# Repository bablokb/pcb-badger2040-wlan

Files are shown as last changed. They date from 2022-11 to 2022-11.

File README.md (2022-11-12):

pcb-badger2040-wlan
===================

A small pcb that allows to add an ESP-01S and/or PCF8523-RTC-breakout
to the back of a Pimoroni Badger2040 (or Tufty2040):

  - Badger2040 with SMD-pins:  
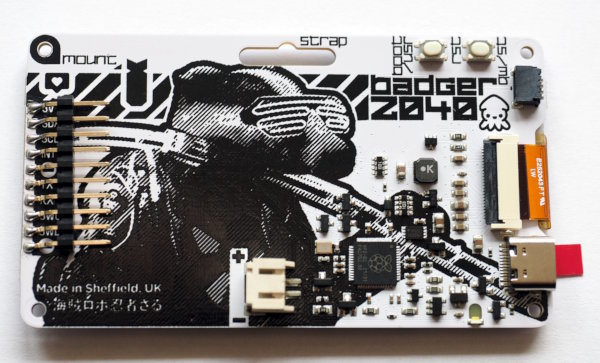
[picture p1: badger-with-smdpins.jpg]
    

  - PCB added:  
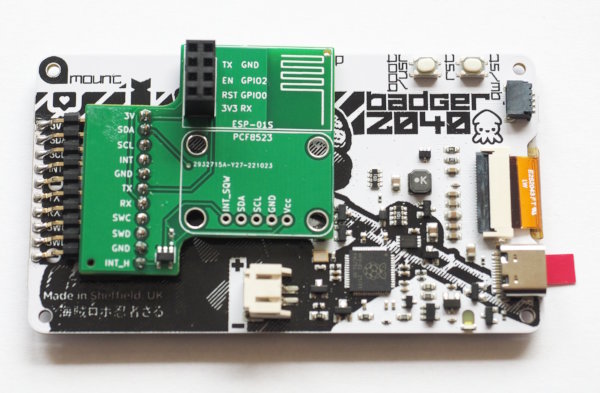
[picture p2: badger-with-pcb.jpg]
    

  - ESP-01S connected:  
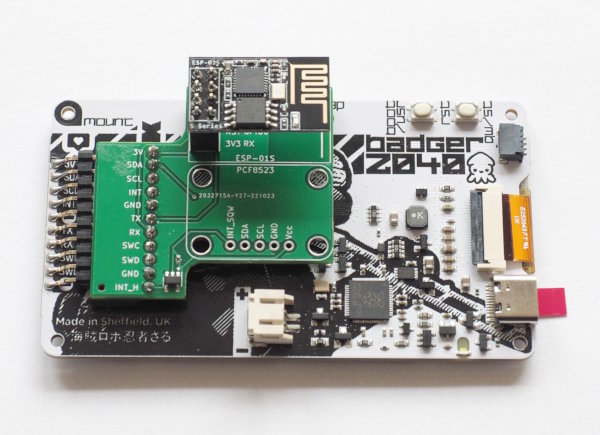
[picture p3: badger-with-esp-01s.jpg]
    

  - Additionally with RTC (PCF8523):  
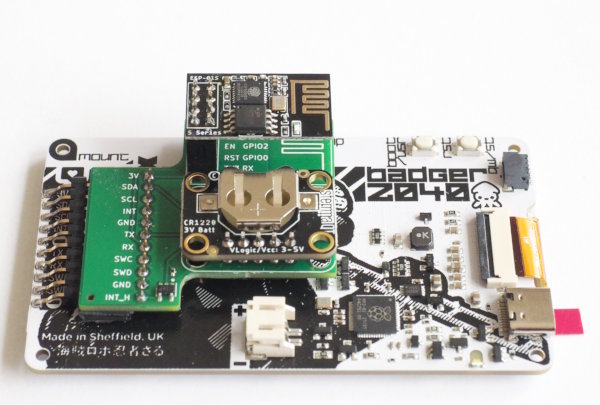
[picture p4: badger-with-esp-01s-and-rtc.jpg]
    

Note that the images show an old Rev 3 version of the PCB.

Design-Files
------------

KiCAD source files are in `badger-2040-wlan.kicad`. Production files
for JLCPCB are in directory `production`. Since the pcb does not
need any SMD-components (in Rev 4), these pcb are really easy
to order (just upload the zip) and cheap (I got five for less
than 7 Euro).

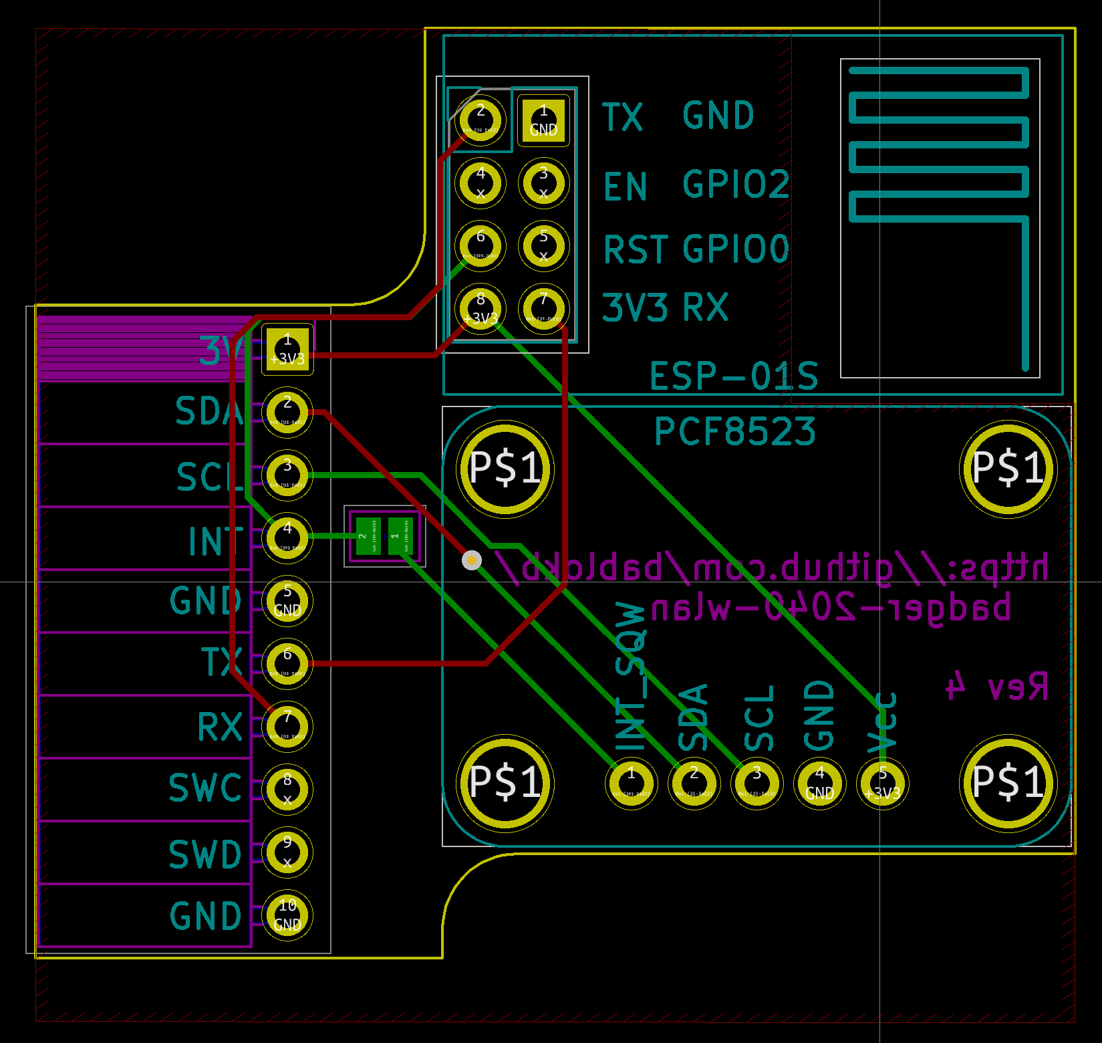
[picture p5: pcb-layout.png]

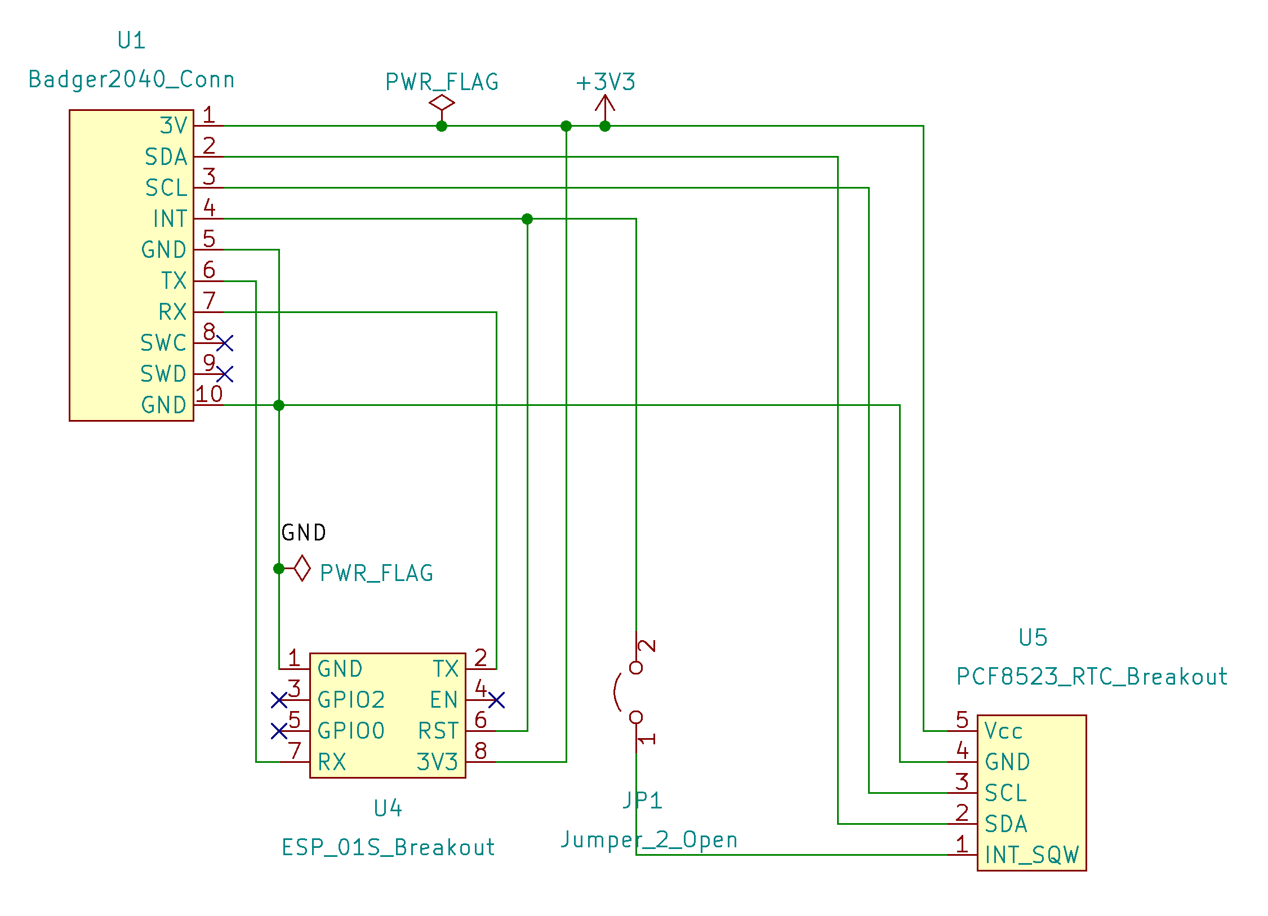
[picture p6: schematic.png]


Hack to wakeup the Badger2040 using the RTC
-------------------------------------------

If you don't use the ESP-01S, you can connect the
RTC-alarm pin to the INT-pin by closing the jumper on the
back. Note that wakeup will only work with battery if you
constantly hold one of the buttons pressed
(see <https://github.com/bablokb/badger2040-button-clamp>).

Also, wakup is currently not implemented in MicroPython.

License
-------

[![CC BY-SA 4.0][cc-by-sa-shield]][cc-by-sa]

This work is licensed under a
[Creative Commons Attribution-ShareAlike 4.0 International
License][cc-by-sa].

[][cc-by-sa]

[cc-by-sa]: http://creativecommons.org/licenses/by-sa/4.0/
[cc-by-sa-image]: https://licensebuttons.net/l/by-sa/4.0/88x31.png
[cc-by-sa-shield]:
https://img.shields.io/badge/License-CC%20BY--SA%204.0-lightgrey.svg

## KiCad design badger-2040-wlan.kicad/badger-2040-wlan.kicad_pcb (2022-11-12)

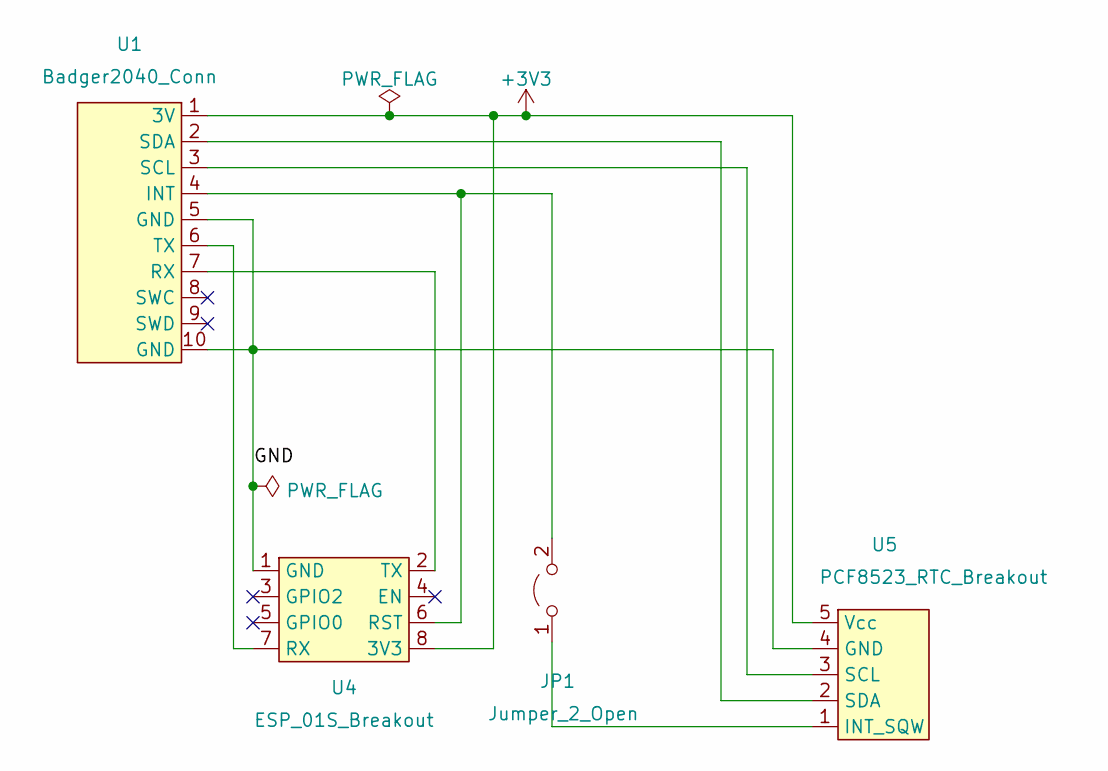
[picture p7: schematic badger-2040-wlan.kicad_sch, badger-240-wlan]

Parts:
JP1: Jumper_2_Open; SolderJumper-2_P1.3mm_Open_Pad1.0x1.5mm
U1: Badger2040_Conn; PinSocket_1x10_P2.54mm_Horizontal_Back
U4: ESP_01S_Breakout
U5: PCF8523_RTC_Breakout; PCF8523_Breakout

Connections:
+3V3: U1.1 (3V), U4.8 (3V3), U5.5 (Vcc)
/GND: U1.5 (GND), U1.10 (GND), U4.1 (GND), U5.4 (GND)
unnamed: JP1.1 (A), U5.1 (INT_SQW)
unnamed: JP1.2 (B), U1.4 (INT), U4.6 (RST)
unnamed: U1.2 (SDA), U5.2 (SDA)
unnamed: U1.3 (SCL), U5.3 (SCL)
unnamed: U1.6 (TX), U4.7 (RX)
unnamed: U1.7 (RX), U4.2 (TX)

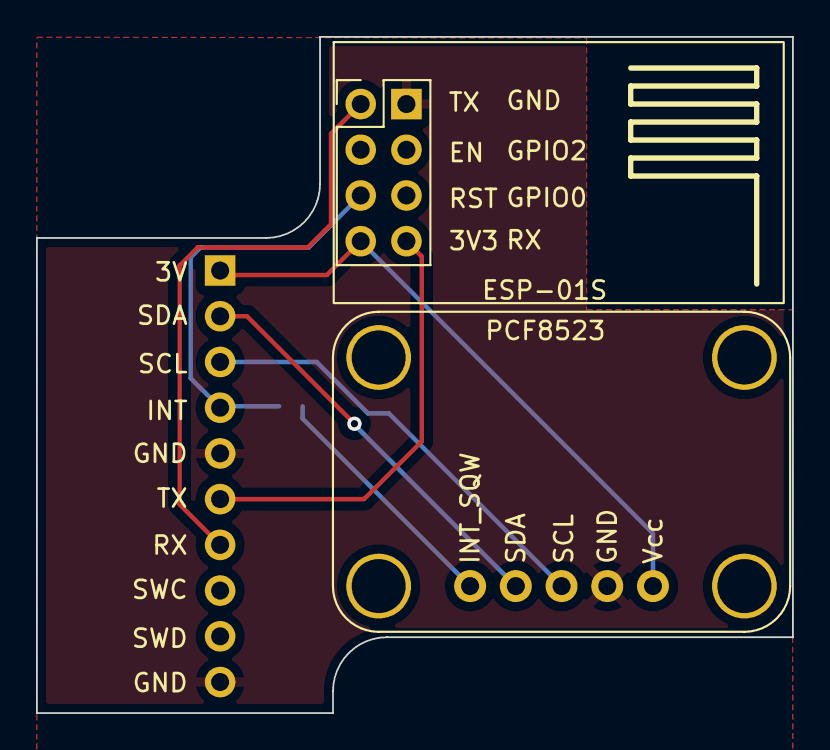
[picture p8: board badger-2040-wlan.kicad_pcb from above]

Board: 2 copper layers, 42.0 x 37.6 mm, 4 parts (1 on the bottom side), 8 nets.

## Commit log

2022-10-22 intial commit
    [badger-2040-wlan.kicad_pcb, badger-2040-wlan.kicad_sch, bom.csv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]
2022-11-12 Rev 4: removed pullup and inverter for RTC (INT_SQW)
    [badger-2040-wlan.kicad_pcb, badger-2040-wlan.kicad_sch, bom.csv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]
